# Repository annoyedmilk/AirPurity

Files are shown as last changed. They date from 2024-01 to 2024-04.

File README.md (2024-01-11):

# AirPurity: Sleek Indoor Air Quality Companion

Welcome to my repository for AirPurity, an innovative, open-source indoor air quality monitor I designed to enhance environmental awareness in personal spaces. This project harnesses the ESP32C3 microcontroller alongside the advanced Bosch BME680 sensor, providing real-time data on air quality, temperature, humidity, and atmospheric pressure, all in a compact and user-friendly design.

My goal with AirPurity is to empower individuals like you and me to understand and improve the air quality in our living and working environments. By being aware of the air we breathe, we can take meaningful steps toward healthier lifestyles.

## Features
- **Accurate Air Quality Monitoring**: Measures various parameters including VOCs, CO2 levels, and particulate matter to keep you informed about your indoor air quality.
- **Temperature and Humidity Sensing**: Monitors the comfort levels of your environment.
- **E-Paper Display**: Offers crisp and energy-efficient readouts.
- **USB-C Powered**: Designed for convenience with a modern USB-C connection for power.
- **Rechargeable Battery**: Ensures portability and ease of use anywhere.
- **Future Expansions**: I'm excited about exploring the Bluetooth and WiFi capabilities of the ESP32C3 to enhance this project further.

## Open Source Commitment
I have made this project completely open-source, hosted right here on GitHub. I invite and welcome collaboration, modification, and distribution of AirPurity. The project is licensed under the MIT License, which guarantees your freedom to use and share it as you see fit, promoting a community-driven approach to better air quality.

I invite you to join me on this journey to make indoor air quality monitoring more accessible and insightful. Whether you're a fellow tech enthusiast, a health-conscious individual, or someone eager to contribute to a meaningful open-source project, your interest and involvement in AirPurity would be greatly appreciated.

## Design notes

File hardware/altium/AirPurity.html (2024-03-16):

Reporting Options

# File in Newer Format

Date | : | 16.03.2024
Time | : | 08:03:26
Filename | : | C:\Users\Andon_Projekt\Documents\AirPurity\hardware\altium\AirPurity.PrjPcb

Version | Warning

Release 23.10

CAUTION - This project contains rules defined using the Constraint Manager. You are seeing this message for two possible reasons. Firstly, this is an older version of the software that does not support this feature, in which case design rules will fall back to being presented as standard, query-based rules. If you save the PCB project in this older version of Altium Designer, all Constraint Manager data structure information will be lost. Secondly, if this software version does support the feature, then you currently don't have the level of Altium Designer Software Subscription (Pro/Enterprise) to be able to edit constraints using the Constraint Manager, in which case it will present rules in view only mode.

This file was generated by a later version of the software

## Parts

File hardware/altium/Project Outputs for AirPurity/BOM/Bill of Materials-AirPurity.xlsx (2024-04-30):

Comment | Description | Designator | LibRef | LCSC Part Number | Quantity
2450AT18A100 | Chip Antenna 0.5dBi 2.4GHz 2W 1206 | ANT1 | 2450AT18A100 | C89334 | 1
GRM155R61E105KA12D | 1uF X5R 0402 Multilayer Ceramic Capacitor | C1, C10, C11, C12, C13, C14, C19, C20, C22, C23, C24, C25, C27, C29, C30, C32, C39 | GRM155R61E105KA12D | C77009 | 17
GRM155R61E475ME15D | 4.7uF X5R 0402 Multilayer Ceramic Capacitor | C2, C3, C4, C26, C31 | GRM155R61E475ME15D | C2858031 | 5
GRM0335C1H150FA01D | 15pF C0G 0201 Multilayer Ceramic Capacitor | C5, C7, C33, C34 | GRM0335C1H150FA01D | C237567 | 4
GRM033R61A104KE15D | 100nF X5R 0201 Multilayer Ceramic Capacitor | C6, C8, C9, C15, C16, C17, C18, C21, C28, C37 | GRM033R61A104KE15D | C76934 | 10
GRM0335C1H100JA01D | 10pF C0G 0201 Multilayer Ceramic Capacitor | C35, C36 | GRM0335C1H100JA01D | C76921 | 2
GRM0335C1H1R0BA01D | 1pF C0G 0201 Multilayer Ceramic Capacitor | C38 | GRM0335C1H1R0BA01D | C85893 | 1
MBR0530T3G | Schottky Barrier Diodes | D1, D4, D5, D6 | MBR0530T3G | C236079 | 4
150060BS75000 | LED Blue 3.2V 0603 | D2 | 150060BS75000 | C5197644 | 1
150060GS75000 | LED Emerald 3.2V 0603 | D3 | 150060GS75000 | C5252984 | 1
0466.500NRHF | Fuse 500mA | F1 | 0466.500NRHF | C151133 | 1
Fiducial | Fiducial | FD1, FD2, FD3, FD4 | Fiducial |  | 4
CX90M-16P | Connector USB2.0 TYPE-C 16POS | J1 | CX90M-16P | C2889324 | 1
524352471 | FPC Connector, 2.0 mm, 0.5 mm, Right Angle | J2 | 524352471 | C122394 | 1
LQP03TN3N9B02D | Inductor 3.9nH | L1 | LQP03TN3N9B02D | C77115 | 1
LQP03TG2N7C02D | Inductor 2.7nH | L2, L3 | LQP03TG2N7C02D | C337946 | 2
1239AS-H-100M=P2 | Inductor 10uH | L4 | 1239AS-H-100M=P2 | C237599 | 1
S2B-PH-SM4-TB(LF)(SN) | Male Header, Pitch 2 mm, 1 x 2 Position | P1 | S2B-PH-SM4-TB(LF)(SN) | C295747 | 1
DMP2240UW-7 | MOSFET P-Channel | Q1 | DMP2240UW-7 | C459548 | 1
SI1308EDL-T1-GE3 | MOSFET N-Channel | Q2 | SI1308EDL-T1-GE3 | C469327 | 1
RC0402FR-075K1L | 5.1kΩ 0402 Chip Resistor | R1, R3, R9, R10 | RC0402FR-075K1L | C105872 | 4
RC0402FR-07150RL | 150Ω 0402 Chip Resistor | R2, R7 | RC0402FR-07150RL | C138054 | 2
RC0402FR-0710KL | 10kΩ 0402 Chip Resistor | R4, R5, R11, R12, R14, R15 | RC0402FR-0710KL | C60490 | 6
RC0402FR-0722RL | 22Ω 0402 Chip Resistor | R6, R8 | RC0402FR-0722RL | C114765 | 2
RC0402FR-073R16L | 3.16Ω 0402 Chip Resistor | R13 | RC0402FR-073R16L | C477688 | 1
PTS636 SK25J SMTR LFS | Tactile Switch SPST | SW1, SW2 | PTS636 SK25J SMTR LFS | C2800965 | 2
TLV70233DBVR | LDO Voltage Regulators 300mALow IQLDO Reg | U1 | TLV70233DBVR | C26833 | 1
MCP73831T-2ACI/OT | IC Controller LI-ION 4.2V | U2 | MCP73831T-2ACI/OT | C424093 | 1
MAX17048G+T10 | Fuel Gauge LI-ION | U3 | MAX17048G+T10 | C2682616 | 1
BME680 | Gas, Humidity, Pressure, Temperature Sensor I²C | U4 | BME680 | C125972 | 1
ESP32-C3FH4 | Bluetooth, WiFi 802.11b/g/n, Bluetooth v5.0 Transceiver Module 2.402GHz ~ 2.48GHz Antenna Not Included Surface Mount | U5 | ESP32-C3FH4 | C2858491 | 1
9H03200031 | Crystal 32.768 kHz | Y1 | 9H03200031 | C90944 | 1
7M40000183 | Crystal 40 MHz | Y2 | 7M40000183 | C331598 | 1

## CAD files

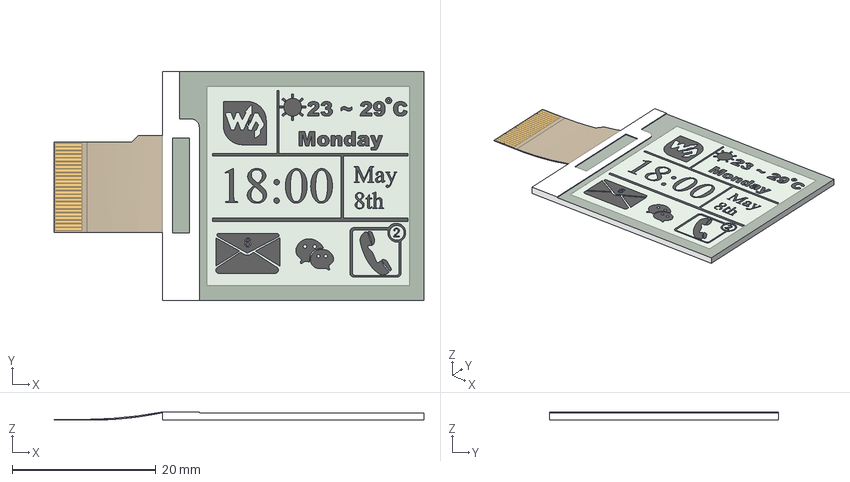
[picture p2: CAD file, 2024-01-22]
hardware/3D Model/Waveshare 1.54 E ink - Display Flat Mount.stp
51.4 x 31.8 x 1.14 mm

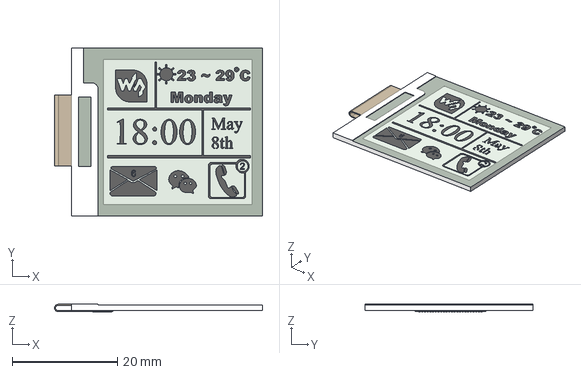
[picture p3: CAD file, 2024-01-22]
hardware/3D Model/Waveshare 1.54 E ink - Display Flush Folded.stp
39.5 x 31.8 x 1.43 mm

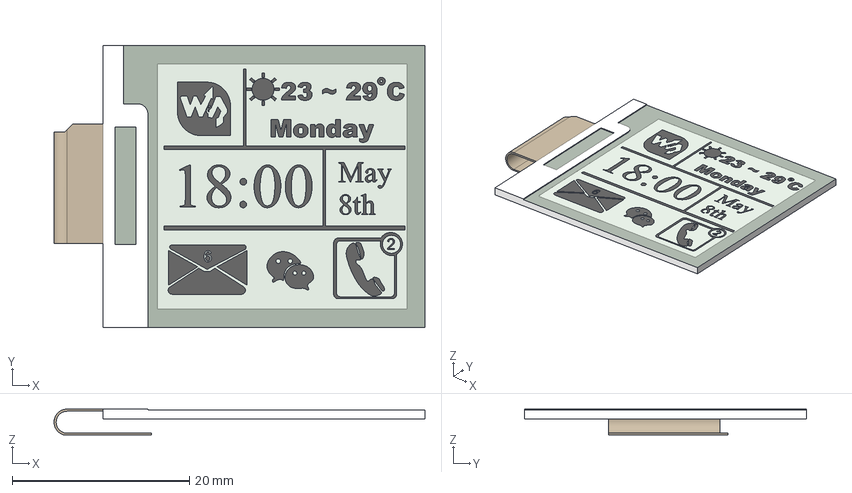
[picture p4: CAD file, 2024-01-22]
hardware/3D Model/Waveshare 1.54 E ink - Display Folded.stp
41.8 x 31.8 x 2.92 mm

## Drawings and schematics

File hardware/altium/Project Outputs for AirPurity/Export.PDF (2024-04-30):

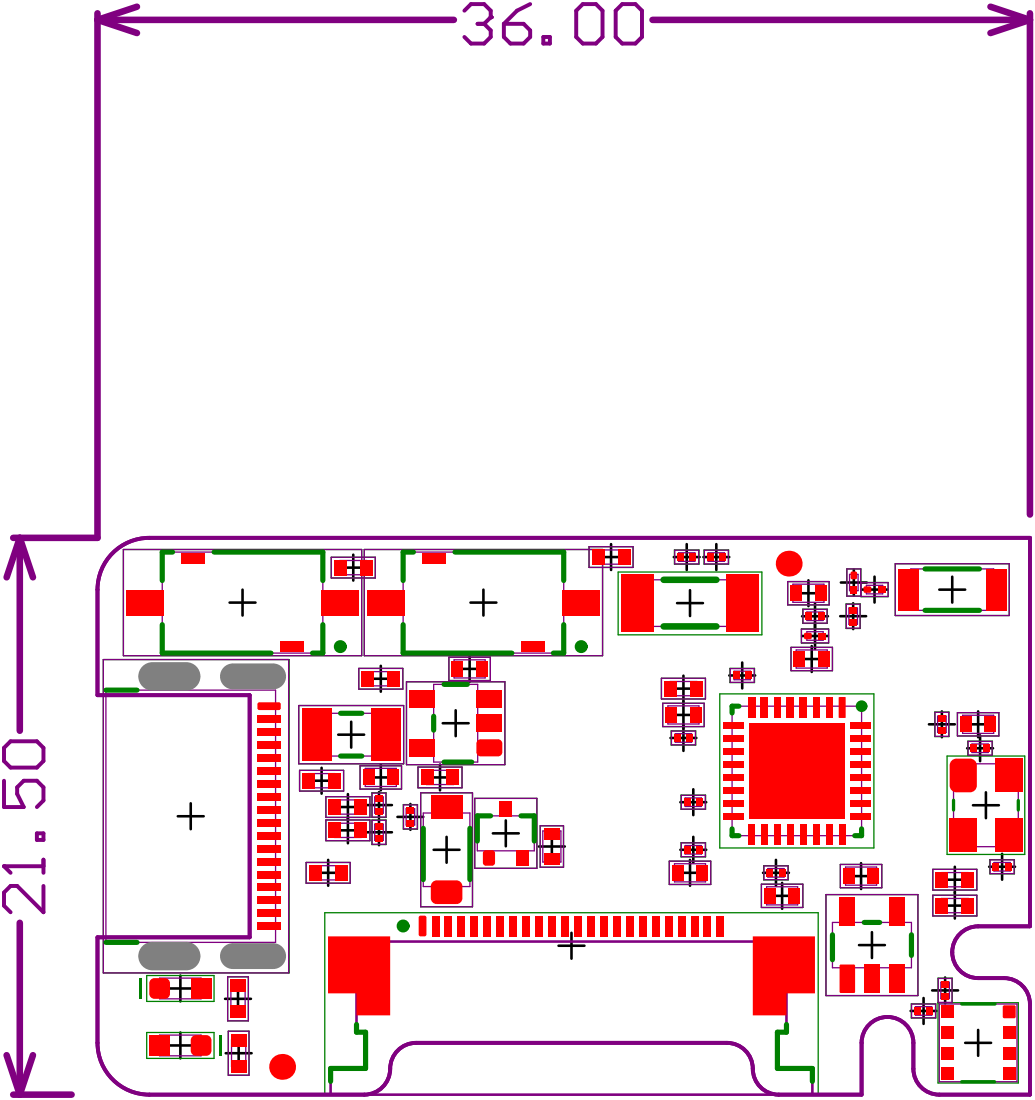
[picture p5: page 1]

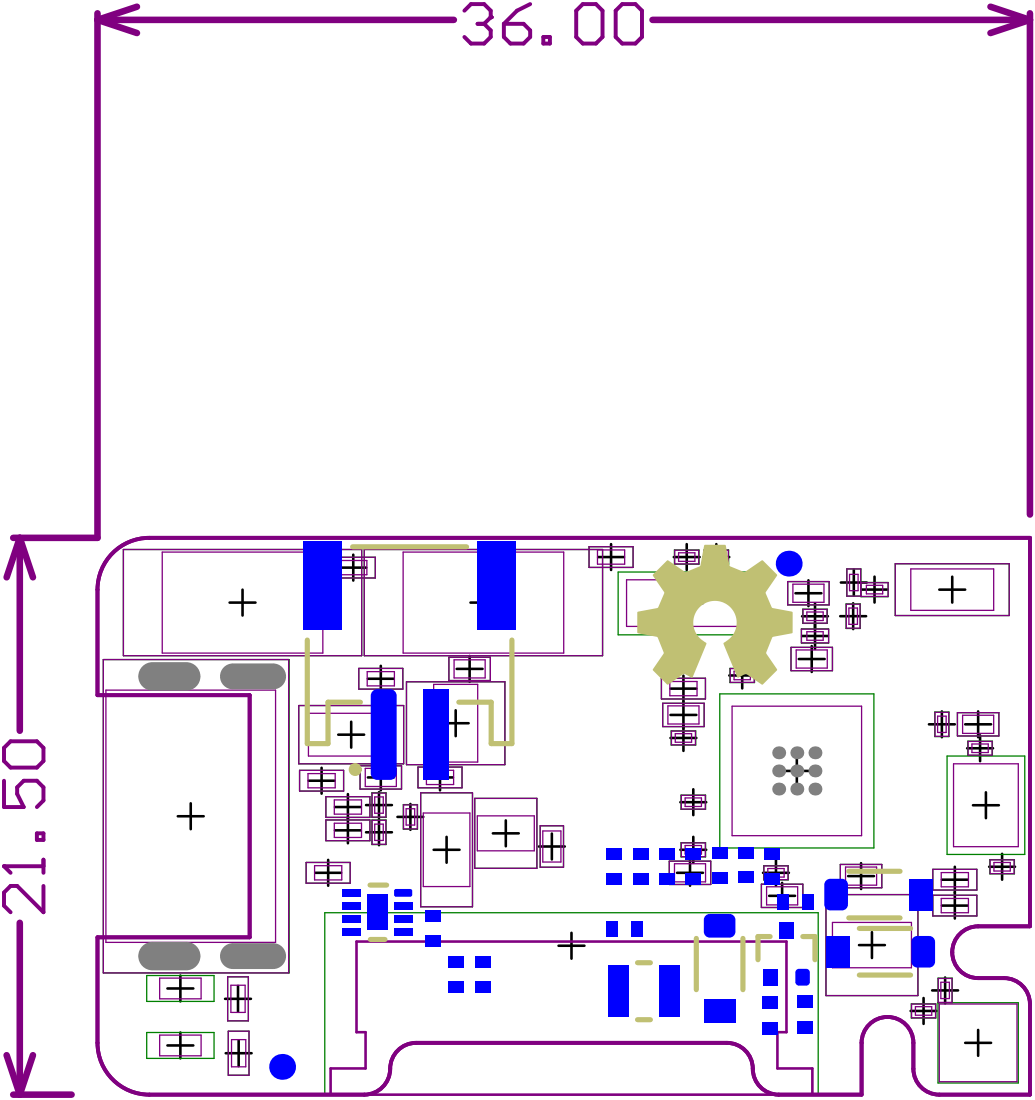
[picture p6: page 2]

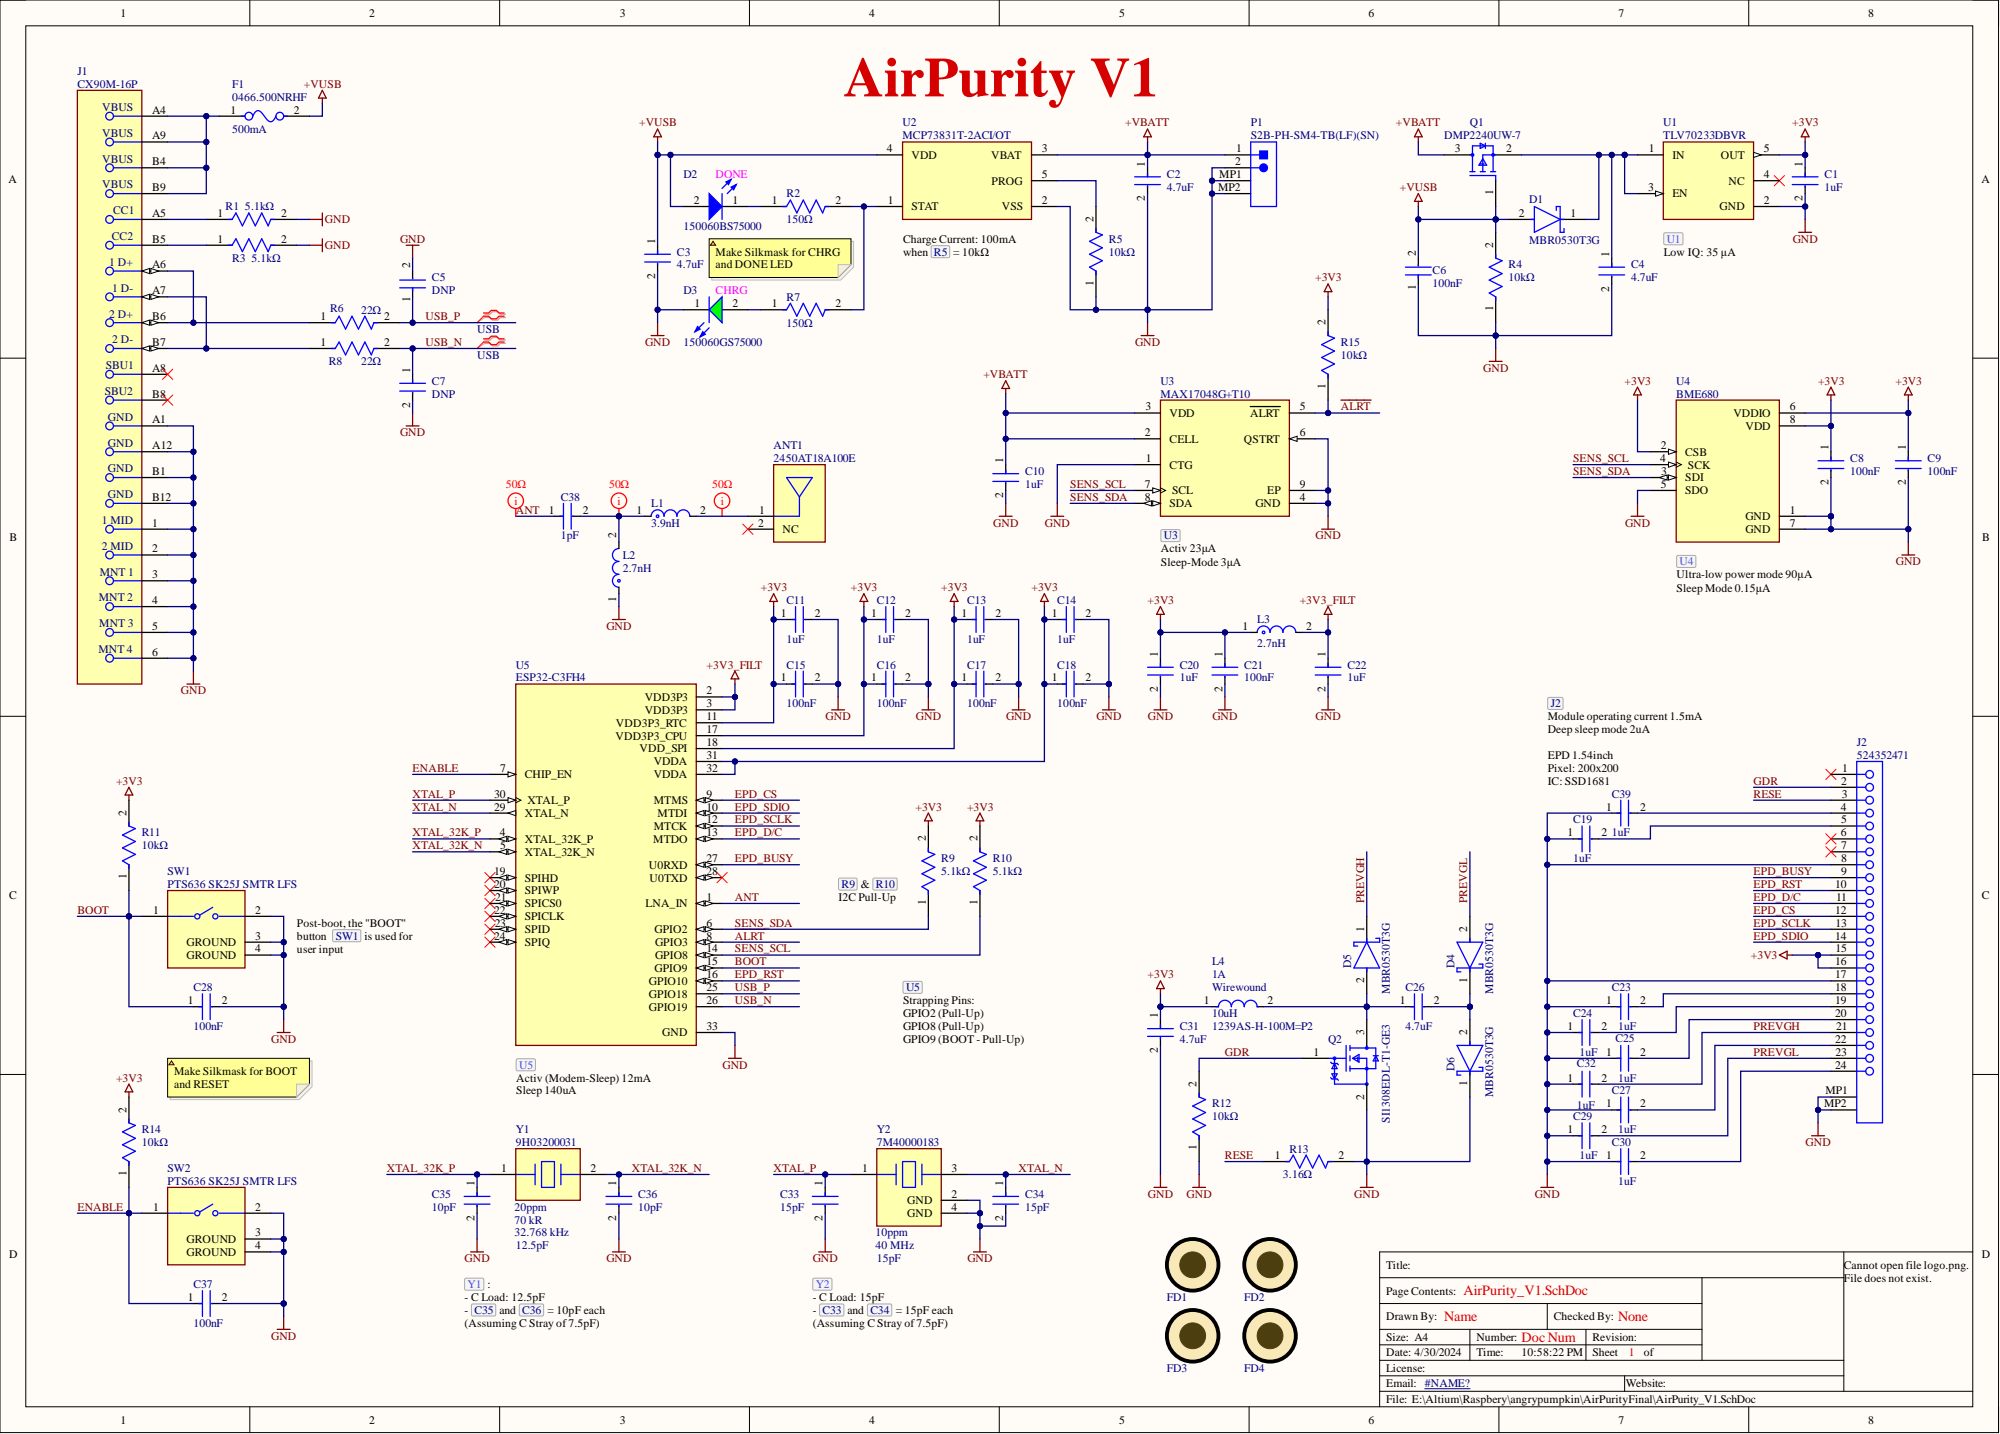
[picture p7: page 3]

MP1
MP2

Make Silkmask for CHRG
and DONE LED

Ultra-low power mode 90μA
Sleep Mode 0.15μA

Post-boot, the "BOOT"
button SW1 is used for
user input

Make Silkmask for BOOT
and RESET

GND

Cannot open file logo.png.
File does not exist.

Page Contents: AirPurity_V1.SchDoc

Drawn By: Name | Checked By: None
Size: A4 | Doc Num Number: | Revision:
Date: 4/30/2024 | Time: 10:58:22 PM | Sheet 1 of

License:
Email: #NAME?
E:\Altium\Raspbery\angrypumpkin\AirPurityFinal\AirPurity_V1.SchDoc

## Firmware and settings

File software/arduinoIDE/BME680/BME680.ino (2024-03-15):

#include <bsec2.h>

#define SDA_PIN 20
#define SCL_PIN 21

void checkBsecStatus(Bsec2 bsec);
void newDataCallback(const bme68xData data, const bsecOutputs outputs, Bsec2 bsec);

Bsec2 envSensor;

void setup() {
    bsecSensor sensorList[] = {
        BSEC_OUTPUT_IAQ,
        BSEC_OUTPUT_STATIC_IAQ,
        BSEC_OUTPUT_CO2_EQUIVALENT,
        BSEC_OUTPUT_BREATH_VOC_EQUIVALENT,
        BSEC_OUTPUT_RAW_TEMPERATURE,
        BSEC_OUTPUT_RAW_PRESSURE,
        BSEC_OUTPUT_RAW_HUMIDITY,
        BSEC_OUTPUT_RAW_GAS,
        BSEC_OUTPUT_STABILIZATION_STATUS,
        BSEC_OUTPUT_RUN_IN_STATUS,
        BSEC_OUTPUT_SENSOR_HEAT_COMPENSATED_TEMPERATURE,
        BSEC_OUTPUT_SENSOR_HEAT_COMPENSATED_HUMIDITY,
        BSEC_OUTPUT_GAS_PERCENTAGE
    };

    Serial.begin(115200);
    Wire.begin(SDA_PIN, SCL_PIN);

    while(!Serial) delay(10);

    if (!envSensor.begin(0x76, Wire)) { // Adjusted to use the specified I2C address
        checkBsecStatus(envSensor);
    }

    if (!envSensor.updateSubscription(sensorList, sizeof(sensorList) / sizeof(sensorList[0]), BSEC_SAMPLE_RATE_LP)) {
        checkBsecStatus(envSensor);
    }

    envSensor.attachCallback(newDataCallback);

    Serial.println("BSEC library version " + String(envSensor.version.major) + "." + String(envSensor.version.minor) + "." + String(envSensor.version.major_bugfix) + "." + String(envSensor.version.minor_bugfix));
}

void loop() {
    if (!envSensor.run()) {
        checkBsecStatus(envSensor);
    }
}

void newDataCallback(const bme68xData data, const bsecOutputs outputs, Bsec2 bsec) {
    if (!outputs.nOutputs) {
        return;
    }

    Serial.println("BSEC outputs:\n\ttimestamp = " + String((int)(outputs.output[0].time_stamp / INT64_C(1000000))));
    for (uint8_t i = 0; i < outputs.nOutputs; i++) {
        const bsecData output = outputs.output[i];
        switch (output.sensor_id) {
        case BSEC_OUTPUT_IAQ:
            Serial.println("\tIAQ = " + String(output.signal));
            Serial.println("\tIAQ Accuracy = " + String((int)output.accuracy));
            break;
        case BSEC_OUTPUT_STATIC_IAQ:
            Serial.println("\tStatic IAQ = " + String(output.signal));
            Serial.println("\tStatic IAQ Accuracy = " + String((int)output.accuracy));
            break;
        case BSEC_OUTPUT_CO2_EQUIVALENT:
            Serial.println("\tCO2 Equivalent = " + String(output.signal) + " ppm");
            Serial.println("\tCO2 Accuracy = " + String((int)output.accuracy));
            break;
        case BSEC_OUTPUT_BREATH_VOC_EQUIVALENT:
            Serial.println("\tBreath VOC Equivalent = " + String(output.signal) + " ppm");
            break;
        case BSEC_OUTPUT_RAW_TEMPERATURE:
            Serial.println("\tRaw Temperature = " + String(output.signal) + " °C");
            break;
        case BSEC_OUTPUT_RAW_PRESSURE:
            Serial.println("\tRaw Pressure = " + String(output.signal) + " Pa");
            break;
        case BSEC_OUTPUT_RAW_HUMIDITY:
            Serial.println("\tRaw Humidity = " + String(output.signal) + " %");
            break;
        case BSEC_OUTPUT_RAW_GAS:
            Serial.println("\tRaw Gas Resistance = " + String(output.signal) + " Ohms");
            break;
        case BSEC_OUTPUT_STABILIZATION_STATUS:
            Serial.println("\tStabilization Status = " + String(output.signal));
            break;
        case BSEC_OUTPUT_RUN_IN_STATUS:
            Serial.println("\tRun-In Status = " + String(output.signal));
            break;
        case BSEC_OUTPUT_SENSOR_HEAT_COMPENSATED_TEMPERATURE:
            Serial.println("\tHeat Compensated Temperature = " + String(output.signal) + " °C");
            break;
        case BSEC_OUTPUT_SENSOR_HEAT_COMPENSATED_HUMIDITY:
            Serial.println("\tHeat Compensated Humidity = " + String(output.signal) + " %");
            break;
        case BSEC_OUTPUT_GAS_PERCENTAGE:
            Serial.println("\tGas Percentage = " + String(output.signal) + " %");
            break;
        default:
            Serial.println("\tUnknown Sensor ID");
            break;
        }
    }
}

void checkBsecStatus(Bsec2 bsec) {
    if (bsec.status < BSEC_OK) {
        Serial.println("BSEC error code : " + String(bsec.status));
    } else if (bsec.status > BSEC_OK) {
        Serial.println("BSEC warning code : " + String(bsec.status));
    }

    if (bsec.sensor.status < BME68X_OK) {
        Serial.println("BME68X error code : " + String(bsec.sensor.status));
    } else if (bsec.sensor.status > BME68X_OK) {
        Serial.println("BME68X warning code : " + String(bsec.sensor.status));
    }
}

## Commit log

2024-01-09 Add Altium project files and component datasheets
    - Imported Altium project template files for the new design.
    - Added datasheets for the main components used in the project,
    including microcontrollers, sensors, and display.
    - This inclusion will assist in design reference and component selection.
    [AirPurity.PcbDoc, AirPurity.PrjPcb, AirPurity.SchDoc]
2024-01-21 Initial Schematic and PCB Design in Altium
    Started the development of the project's schematic and PCB layout using Altium Designer. This initial commit includes the basic schematic framework and a preliminary PCB layout. The schematic current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
    [AirPurity.PrjPcb, AirPurity.SchDoc]
2024-01-22 Enhanced Basic Layout in Schematic and PCB
    Expanded the initial schematic and PCB layout in Altium. Added key components and preliminary connections in the schematic. Refined component placement in the PCB layout, setting the stage for detail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
    [AirPurity.SchDoc]
2024-01-22 Added 3D Model for Display
    Integrated a 3D model for the display into the PCB layout in Altium. This addition enhances the design's visualization and aids in assessing spatial arrangements and potential conflicts with other co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
    [Waveshare 1.54 E ink - Display Flat Mount.stp, Waveshare 1.54 E ink - Display Flush Folded.stp, Waveshare 1.54 E ink - Display Folded.stp]
2024-01-22 Added 1.5inch e-Paper PDF
    Switching to an alternative e-Paper from Waveshare
2024-01-22 Extensive Schematic Overhaul and Pre-Review Preparation
    Dedicated significant effort to revising and enhancing the schematic in preparation for the first review. This update includes a thorough refinement of the circuit design, addition of new components,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
    [AirPurity.PrjPcb, AirPurity.SchDoc, Bill of Materials-AirPurity.xlsx]
2024-01-24 Approaching Finalization of Schematic Draft for AirPurity Module
    Significant progress has been made on the schematic draft of the AirPurity module, nearing its completion. Extensive thought and planning have been devoted to the PCB layout, particularly focusing on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
    [AirPurity.SchDoc]
2024-01-25 Schematic Finalized and Ready for Review
    The latest update brings the schematic to a stage where it's ready for a comprehensive review. Key developments include the addition of a fuel gauge for the battery, enhancing our power management capabilities. Both the sensor and the fuel gauge are now configured over I2C, ensuring efficient communication, while the display continues to operate on a separate 3-wire SPI interface for optimal performance.
    Additionally, bootstrapping pins have been set to float, addressing potential initialization issues. All available pins have been utilized to maximize functionality and interface options. This update solidifies the design, paving the way for a detail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
    [AirPurity.PrjPcb, AirPurity.SchDoc]
2024-01-29 Update Components for LCSC Availability and Complete Schematic
    This commit includes the following key changes:
    1. Component Replacement: All components in the design have been updated to ensure availability at LCSC. This includes substituting parts that were previously sourced from other suppliers with equivalent or better components available through LCSC. Each component has been carefully selected to maintain or enhance the performance and reliability of the design.
    2. Schematic Finalization: The schematic has been thoroughly reviewed and finalized. This includes checking all connections, ensuring correct part values, and verifying that the design meets all specified requirements. The fi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
    [AirPurity.PrjPcb, AirPurity.SchDoc, Bill of Materials-AirPurity.xlsx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]
2024-01-29 Refinement of Schematic and Component Adjustments
    This commit introduces a set of minor yet significant refinements:
    1. Schematic Tweaks: Minor adjustments have been made to the schematic for enhanced clarity and functionality. These include optimizing trace routes, revising component labels for better readability, and minor corrections to ensure alignment with design standards.
    2. Component Updates: A few components have been replaced or adjusted to better suit the design requirements and to ensure greater availability. This includes selecting alternative parts from LCSC that are more cost-effective or offer better performance.
    These small changes are part of our ongoing effort to optimi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
    [AirPurity.SchDoc, Bill of Materials-AirPurity.xlsx, LCSC-BOM.csv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]
2024-01-29 Initiation of Custom Integrated Library Development
    In this commit, we embark on the development of a custom integrated library for our project. Key highlights include:
    1. Foundation Setup: Established the basic structure of the integrated library. This includes setting up directories, initializing standard file formats, and defining the initial set of components to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
    2. Component Inclusion: Began populating the library with essential components. Initial focus is on the components that are unique to our project or those that are frequently used. Each component ent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
    [AirPurity.SchDoc, Bill of Materials-AirPurity.xlsx]
2024-02-11 Update Rules and Template and Library
    Updated Rules Templates and Library
    [AirPurity.PrjPcb, AirPurity.SchDoc, AirPurity_V1.SchDoc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]
2024-02-12 Updated Layout
    [AirPurity_V1.SchDoc]
2024-02-12 Update PCB
    Updated PCB and Library Files
    [AirPurity_V1.SchDoc]
2024-03-05 Implement BME680 Sensor Integration
    This commit introduces the initial integration of the BME680 sensor with the ESP32-C3 for the AirPurity project. The implementation includes setting up the I2C bus on custom pins and configuring the 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
    Key features include:
    - Initialization of the I2C bus on ESP32-C3 custom pins (SDA_PIN 20, SCL_PIN 21).
    - Configuration of the BME680 sensor for oversampling and IIR filter settings to optimize measurement accuracy.
    - Implementation of a continuous measurement loop to read and output temperature, humidity, pressure, gas resistance, and approximate altitude based on sea-level pressu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
2024-03-14 Small Update
    Small Update
    [AirPurity_V1.SchDoc, Bill of Materials-AirPurity.xlsx]
2024-03-14 Small Updates
    Small updates
    [AirPurity_V1.SchDoc, Bill of Materials-AirPurity.xlsx]
2024-03-15 Implement BSEC Integration for Sensor Readings
    This commit transitions our environmental sensor readings from the standard Arduino library to the Bosch Sensortec Environmental Cluster (BSEC) software library. This change allows for more sophistic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
    Key Changes:
    - Integrated BSEC library for advanced environmental data processing.
    - Configured sensor outputs to include IAQ, CO2 equivalent, VOC equivalents, and raw sensor data (temperature, pressure, humidity, gas resistance).
    - Implemented callback function for new data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
2024-03-16 Updated Schematic
    Removed switching from USB to Battery
    [AirPurity_V1.SchDoc]
2024-03-18 New Antenna
    Chip Antenna 0.5dBi 2.4GHz 2W 1206 Package
2024-04-06 Update Layout
    Update
    [AirPurity_V1.SchDoc]
2024-04-28 Schematic Corrections and Layout Revision
    Addressed significant errors discovered in the schematic. Recommended a thorough review at this juncture. Also, made corresponding adjustments to the layout accordingly.
    [AirPurity_V1.SchDoc, Bill of Materials-AirPurity.xlsx]
2024-04-30 Finished PCB Layout
    [AirPurity.GBL, AirPurity.GBO, AirPurity.GBP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]
2024-06-04 Revert "Update"
    This reverts commit 5f5baee09683d1e61508e9af4d2288cef4860fcb.
    [AirPurity.GBL, AirPurity.GBO, AirPurity.GBP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]
